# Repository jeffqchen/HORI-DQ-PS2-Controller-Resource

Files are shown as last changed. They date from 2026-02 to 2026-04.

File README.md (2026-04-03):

# DIY Accessories for HORI Dragon Quest PlayStation 2 Controller



I have bought two of the HORI Dragon Quest PlayStation 2 controllers without the base and the cable. I've been meaning to create those on my own over the years. Finally, I've made it happen.

# [3D Printed Base](./Stand%20Base)

 

I've observed photos from the internet and created this base from the impression. It is not 100% accurate but is very close.

# [Controller Cable Adapter](./Mini%20DIN%20to%20PS%20Plug%20Adapter)

 

This controller has a non-standard Mini DIN 8 pin connector. To connect to the PS2, you must use the enclosed cable. Without the cable, this controller is unusable.

This adapter follows the asthetics of the official controller plug, and does not intefere with the memory card.

 

--------
Shield: [][cc-by-sa]

This work is licensed under a
[Creative Commons Attribution-ShareAlike 4.0 International License][cc-by-sa].

[][cc-by-sa]

[cc-by-sa]: http://creativecommons.org/licenses/by-sa/4.0/
[cc-by-sa-image]: https://licensebuttons.net/l/by-sa/4.0/88x31.png
[cc-by-sa-shield]: https://img.shields.io/badge/License-CC%20BY--SA%204.0-lightgrey.svg

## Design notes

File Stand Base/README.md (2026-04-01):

# 3D Printed Base

 

This base is very easy to print. No supported is needed.

## Versions

I've created two versions:

- Base with logo.stl - for multi-color printers 
- Base without logo.stl - for single color printers
  - (requires DQ Logo.stl printed separately in a different color, attach with super glue)

## Pads



Aside from the pads you can add to the bottom, I recommend adding pads inside the cavity like the photo above, to avoid any potential of involuntary movement or scratching the controller, plus providing better grip.

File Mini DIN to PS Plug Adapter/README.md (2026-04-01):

# Controller Cable Adapter



 

This controller has a non-standard Mini DIN 8 pin connector. To connect to the PS2, you must use the enclosed cable. Without the cable, this controller is unusable.

This adapter follows the asthetics of the official controller plug, and does not intefere with the memory card.

 

## Parts

- PCB: [Gerber File](./PCB/gerber/DQ%20PS2%20Controller%20Adapter.zip)
- 8 pin Mini DIN Female Recepticle, Through Hole - [Link](https://github.com/jeffqchen/JeffParts/blob/main/Connectors/Mini%20DIN/Female/8%20Pin/info.md)
- PlayStation Controller Plug, Male Pins, Right Angle - [Link](https://github.com/jeffqchen/JeffParts/blob/main/Connectors/PlayStation%20Controller%20Port/Male%20Plug/info.md)
- 3D Printed Shell: [STL Files](./Shell)
- M2x20mm screw and hex nut - [Link](https://github.com/jeffqchen/JeffParts/blob/main/Parts/M2%20M3%20Hex%20Screw%20%26%20Nut/info.md)
- 8 pin Mini DIN Cable, Male, Straight - [Link](https://github.com/jeffqchen/JeffParts/blob/main/Cable/Mini%20DIN/8%20Pin/Male/Straight/info.md)

## Assembly

### PCB



Pay attention the silkscreen when populating the connector.

Make sure the PlayStation Plug is soldered as inward as possible, as shown in the picture.

### Shell

First, push the PlayStation plug through from the inside of the inner shell. There will be resistence, since there are hooks designed to prevent the plug from backing out.

Then, close the outer shell onto the assembly. Make sure there is no gap between the shell.

Lastly, thread the M2 screws from the outer shell into the inner shell, then tighten it down with the nuts on the other side.

## Misc

This controller used the outer shielding of the Mini DIN cable as the GROUND for the rumble motors. If your cable did not connec that, there will be no rumble effects.

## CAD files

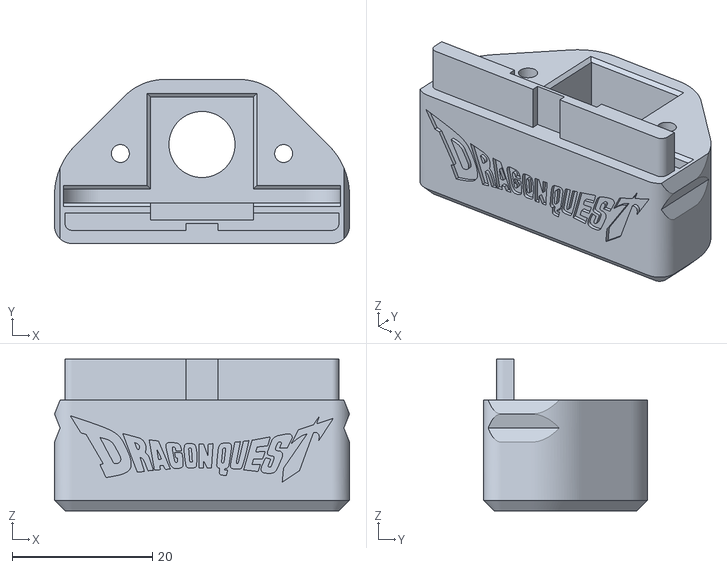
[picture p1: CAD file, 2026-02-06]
Mini DIN to PS Plug Adapter/Shell/Shell Outer.stl
42.0 x 23.3 x 21.6

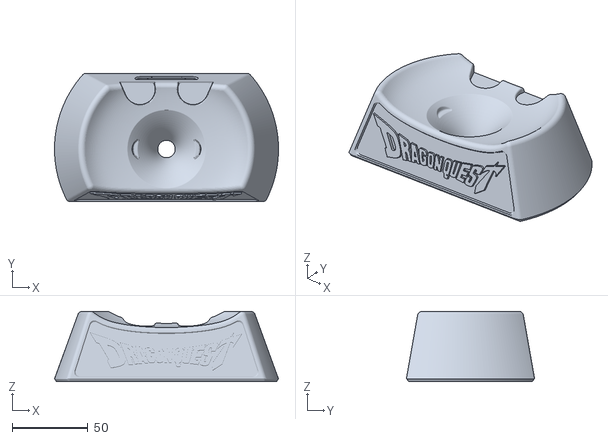
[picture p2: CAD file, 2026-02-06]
Stand Base/Base with logo.stl
147.5 x 84.4 x 46.3

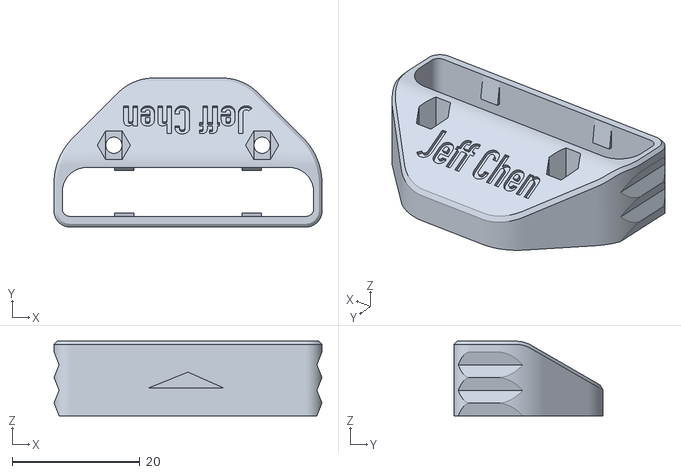
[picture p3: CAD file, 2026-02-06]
Mini DIN to PS Plug Adapter/Shell/Shell Inner.stl
42.0 x 23.3 x 11.7

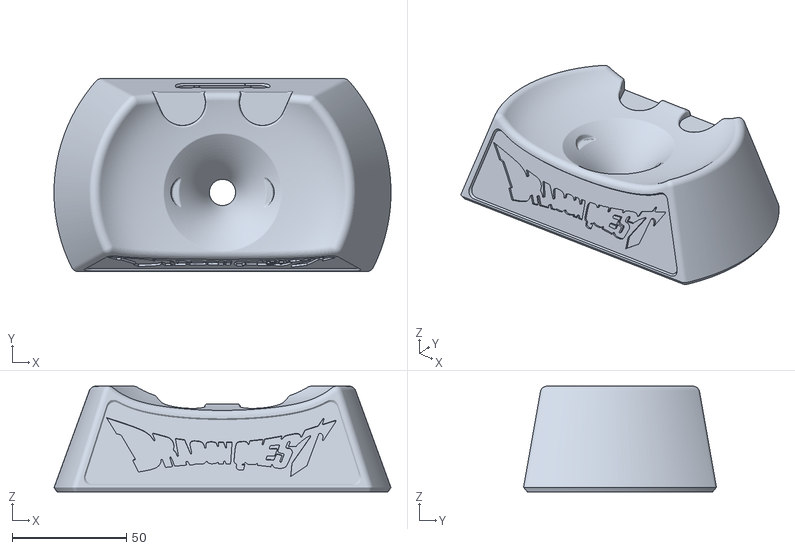
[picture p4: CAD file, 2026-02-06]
Stand Base/Base without logo.stl
147.5 x 84.4 x 46.3

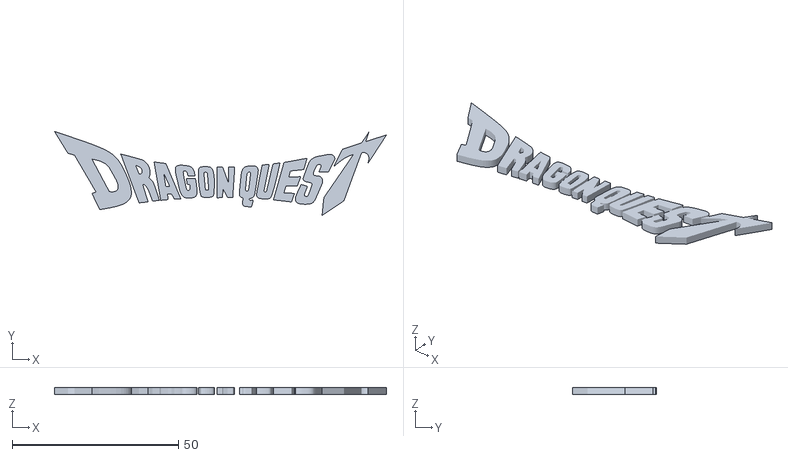
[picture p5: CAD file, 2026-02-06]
Stand Base/DQ Logo.stl
99.7 x 25.2 x 2.00

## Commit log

2026-02-06 Packed up gerber file
2026-04-01 Enhance README with images and descriptions
    Added images and detailed descriptions for the 3D printed base and controller cable adapter for the HORI Dragon Quest PS2 controller.
2026-04-01 Add README for 3D Printed Base
    Added detailed information about the 3D printed base, including images, versions, and recommendations for pads.
2026-04-01 Update README with attachment instructions for logo
    Clarified instructions for single color printer version.
2026-04-01 Fix links in README.md for PCB and Shell
2026-04-01 Update Mini DIN connector description in README
2026-04-01 Update PS Controller Connector description in README
2026-04-01 Add link for 8 pin Mini DIN Cable, Male, Straight
2026-04-01 Enhance README with assembly instructions
    Added assembly instructions for PCB and shell.
2026-04-01 Update README with grounding information for rumble motors
    Added information about the grounding of rumble motors.

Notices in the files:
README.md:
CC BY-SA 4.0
